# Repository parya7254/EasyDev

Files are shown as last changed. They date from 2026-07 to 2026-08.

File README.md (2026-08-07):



# EasyDev
A RP2040 Dev Board featuring 43 exposed pins along with 16 MB of flash storage! Can support up to (not recommended) 1A of power draw on VBUS! Features 29 programmable GPIO pins so that you have plenty of pins for plenty of connecting and tinkering and also a onboard NeoPixel-compatible addressable RGB LED with a exposed pin dedicated for connecting other addressable LEDs to the board without sacrificing a GPIO!




# Why?
I was thinking of making some PCBs, and I thought, why not try something advanced and also something that you have been wanting to do for a while now? And that's when I came up with the idea of making my own RP2040 dev board (basically a Raspberry Pi Pico) starting from scratch. So I did, and learned a lot along the way! Making this devboard will definitely change the way I make PCBs in the future especially because of all the things that I learned from designing this.

# Using the EasyDev Devboard:
Using EasyDev is pretty similar to using other devboards. To use it simply connect the USB port on the devboard to your computer via a USB-C to USB-C/A cable. Then, simply write code to it like you would to a normal devboard/Arduino. To write the code, you can use CircuitPython/Micropython to program it as those are commonly used programming languages for RP2040 devboard, but if you prefer Arduino IDE, you can also use it. Then, if your program needs any connecting to external components, use 2.54mm dupont jumper wires to connect the parts to your devboard!

# Assembly:
The EasyDev devboard comes preassembled <ins>except for the header pins.</ins> You will have to solder the header pins on yourself. The max temperature recommended for soldering is 350 Degrees Celsius, but you should keep the temperature as low as possible <ins> to avoid damaging the PCB,</ins> but not too low where the solder won't properly melt and flow smoothly.

# How it Works:
If you are curious of how this devboard works, well you are in the right spot! When you connect the devboard to your computer, power goes through something called a LDO (Low Dropout Regulator) which, in our case, will keep the voltage going to the rest of the board at 3.3V. But why 3.3V, you might ask. Well, this is because the chip/microcontroller that the devboard has uses 3.3V logic and can only take 3.3V of power, your USB port has 5V of power, directly wiring the USB pins to the chip would blow it up! Then the power goes through decoupling capacitors which are like tiny batteries and then the capacitors help keep stable voltages to the RP2040 chip in case the voltage drops.  Then, there are pins on the chip called GPIOs (General Purpose Input/Output) that you can control with code. Those pins are wired to the header pins on the left and right-hand side. And then the USB data lines are also connected to the RP2040 so that the computer and the devboard can communicate with each other and to upload code to the board. And after you program the board, you can connect parts to the pins like motors, LEDs, etc. using some wires and/or a breadboard!

# PCB




# Schematic


# BOM
Parts used for PCBA:
| Item # | Part Name | JLC Part # | Source | Cost (USD) | Link |
| -----: | :--- | :--- | :----- | ---: | :--- |
| 1 | 1uF 25V X5R ±10% 0402 MLCC Capacitor | **C52923** | JLCPCB | $0.2650 | [https://jlcpcb.com/partdetail/53938-CL05A105KA5NQNC/C52923](https://jlcpcb.com/partdetail/53938-CL05A105KA5NQNC/C52923) |
| 2 | 100nF 16V X7R ±10% 0402 MLCC Capacitor | **C1525** | JLCPCB | $0.2915 | [https://jlcpcb.com/partdetail/1877-CL05B104KO5NNNC/C1525](https://jlcpcb.com/partdetail/1877-CL05B104KO5NNNC/C1525) |
| 3 | 10µF 10V X5R ±10% 0603 MLCC Capacitor | **C19702** | JLCPCB | $0.4080 | [https://jlcpcb.com/partdetail/20411-CL10A106KP8NNNC/C19702](https://jlcpcb.com/partdetail/20411-CL10A106KP8NNNC/C19702) |
| 4 | 33pF 50V C0G ±5% 0402 MLCC Capacitor | **C1562** | JLCPCB | $0.1410 | [https://jlcpcb.com/partdetail/1914-0402CG330J500NT/C1562](https://jlcpcb.com/partdetail/1914-0402CG330J500NT/C1562) |
| 5 | WS2812B-2020V6 RGB LED (Built-in IC) | **C52917434** | JLCPCB | $0.8118 | [https://jlcpcb.com/partdetail/Worldsemi-WS2812B_2020V6/C52917434](https://jlcpcb.com/partdetail/Worldsemi-WS2812B_2020V6/C52917434) |
| 6 | USB Type-C Connector (16P, Right Angle SMT) | **C165948** | JLCPCB | $0.9205 | [https://jlcpcb.com/partdetail/Korean_HropartsElec-TYPE_C_31_M12/C165948](https://jlcpcb.com/partdetail/Korean_HropartsElec-TYPE_C_31_M12/C165948) |
| 7 | 5.1kΩ 0402 ±1% Resistor | **C25905** | JLCPCB | $0.0670 | [https://jlcpcb.com/partdetail/26648-0402WGF5101TCE/C25905](https://jlcpcb.com/partdetail/26648-0402WGF5101TCE/C25905) |
| 8 | 27Ω 0402 ±1% Resistor | **C138021** | JLCPCB | $0.1034 | [https://jlcpcb.com/partdetail/YAGEO-RC0402FR0727RL/C138021](https://jlcpcb.com/partdetail/YAGEO-RC0402FR0727RL/C138021) |
| 9 | 1kΩ 0402 ±1% Resistor | **C11702** | JLCPCB | $0.0800 | [https://jlcpcb.com/partdetail/12256-0402WGF1001TCE/C11702](https://jlcpcb.com/partdetail/12256-0402WGF1001TCE/C11702) |
| 10 | 10kΩ 0402 ±1% Resistor | **C60490** | JLCPCB | $0.1160 | [https://jlcpcb.com/partdetail/YAGEO-RC0402FR0710KL/C60490](https://jlcpcb.com/partdetail/YAGEO-RC0402FR0710KL/C60490) |
| 11 | 4×3mm SMT Tactile Switch | **C720477** | JLCPCB | $0.2760 | [https://jlcpcb.com/partdetail/XUNPU-TS_1088AR02016/C720477](https://jlcpcb.com/partdetail/XUNPU-TS_1088AR02016/C720477) |
| 12 | RP2040 Microcontroller | **C2040** | JLCPCB | $4.9250 | [https://jlcpcb.com/partdetail/RaspberryPi-RP2040/C2040](https://jlcpcb.com/partdetail/RaspberryPi-RP2040/C2040) |
| 13 | NCP1117ST33T3G 3.3V LDO Regulator | **C26537** | JLCPCB | $1.1680 | [https://jlcpcb.com/partdetail/onsemi-NCP1117ST33T3G/C26537](https://jlcpcb.com/partdetail/onsemi-NCP1117ST33T3G/C26537) |
| 14 | W25Q16JVUXIQ 16Mbit SPI Flash | **C2843335**  | JLCPCB | $10.1720 | [https://jlcpcb.com/partdetail/WinbondElec-W25Q16JVUXIQ/C2843335](https://jlcpcb.com/partdetail/WinbondElec-W25Q16JVUXIQ/C2843335) |
| 15 | 12MHz SMD Crystal | **C9002** | JLCPCB | $0.4750 | [https://jlcpcb.com/partdetail/YXC_CrystalOscillators-X322512MSB4SI/C9002](https://jlcpcb.com/partdetail/YXC_CrystalOscillators-X322512MSB4SI/C9002) |

# OLD PCB!!


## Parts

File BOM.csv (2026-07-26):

JLCPCB BOM Tool - BOM Matching
BOM name：EasyDev-PCBA-BOM-JLCPCB-Format-JLCPCB Assembly Order.xlsx |  |  | Download Time：2026-07-27 05:19:50 |  |  |  | * Our matching results are updated in real-time, but stock and prices may change. If it's been over 24 hours, please re-match before placing your order.
PCB Assembled Qty：5 |  |  | Est. Total Price：20.2202
Your BOM |  |  |  |  | Matched Parts |  |  |  |  |  |  | Order Information
Top Designator | Bottom Designator | Comment | Footprint | JLCPCB Part # | Matches | Part # | Manufacturer | Footprint | Description | Category | Warning | JLCPCB Part # | Product link | Lib Type | Qty | Source | Total Price ($)
C1,C10 |  | 1uF | C_0402_1005Metric |  | Select by Customer | CL05A105KA5NQNC | Samsung Electro-Mechanics | 0402 | 1uF 25V X5R ±10% 0402 Multilayer Ceramic Capacitors MLCC - SMD/SMT ROHS | Multilayer Ceramic Capacitors MLCC - SMD/SMT |  | C52923 | https://jlcpcb.com/partdetail/53938-CL05A105KA5NQNC/C52923 | Basic | 10 | 10 JLCPCB | 0.265
C7,C8,C17,C4,C12,C9,C11,C5,C3,C2,C6 |  | 0.1uF | C_0402_1005Metric |  | Select by Customer | CL05B104KO5NNNC | Samsung Electro-Mechanics | 0402 | 100nF 16V X7R ±10% 0402 Multilayer Ceramic Capacitors MLCC - SMD/SMT ROHS | Multilayer Ceramic Capacitors MLCC - SMD/SMT | 1.The comment (CL05B104KO5NNNC) of this part does not match the one (0.1uF) provided in your BOM. Please confirm; | C1525 | https://jlcpcb.com/partdetail/1877-CL05B104KO5NNNC/C1525 | Basic | 55 | 55 JLCPCB | 0.2915
C14,C13 |  | 10uF | C_0603_1608Metric |  | Select by Customer | CL10A106KP8NNNC | Samsung Electro-Mechanics | 0603 | 10V 10uF X5R ±10% 0603 Multilayer Ceramic Capacitors MLCC - SMD/SMT ROHS | Multilayer Ceramic Capacitors MLCC - SMD/SMT |  | C19702 | https://jlcpcb.com/partdetail/20411-CL10A106KP8NNNC/C19702 | Basic | 10 | 10 JLCPCB | 0.408
C16,C15 |  | 33pF | C_0402_1005Metric |  | Select by Customer | 0402CG330J500NT | FH (Guangdong Fenghua Advanced Tech) | 0402 | 33pF 50V C0G ±5% 0402 Multilayer Ceramic Capacitors MLCC - SMD/SMT ROHS | Multilayer Ceramic Capacitors MLCC - SMD/SMT |  | C1562 | https://jlcpcb.com/partdetail/1914-0402CG330J500NT/C1562 | Basic | 10 | 10 JLCPCB | 0.141
D1 |  | WS2812B-2020 | LED_WS2812B-2020_PLCC4_2.0x2.0mm |  | Select by Customer | WS2812B-2020-V6 | Worldsemi | SMD2020-4P | Built-in power-on reset circuit、Built-in power-on reset circuit、Integrated intelligent reverse connection protection function SMD2020-4P RGB LEDs(Built-in IC) ROHS |  |  | C52917434 | https://jlcpcb.com/partdetail/Worldsemi-WS2812B_2020V6/C52917434 | Extended | 9 | 9 JLCPCB | 0.8118
J1 |  | USB_C_Receptacle_USB2.0_14P | USB_C_Receptacle_HRO_TYPE-C-31-M-12 |  | Select by Customer | TYPE-C-31-M-12 | Korean Hroparts Elec | SMD | -30℃~+80℃ 1 10,000 cycles 16P 20V 5A 7.35mm Female Surface Mount, Right Angle Type-C SMD USB Connectors ROHS | USB Connectors |  | C165948 | https://jlcpcb.com/partdetail/Korean_HropartsElec-TYPE_C_31_M12/C165948 | Extended | 5 | 5 JLCPCB | 0.9205
R1,R2 |  | 5.1K | R_0402_1005Metric |  | Select by Customer | 0402WGF5101TCE | UNI-ROYAL(Uniroyal Elec) | 0402 | -55℃~+155℃ 5.1kΩ 50V 62.5mW Thick Film Resistor ±1% ±100ppm/℃ 0402 Chip Resistor - Surface Mount ROHS | Chip Resistor - Surface Mount |  | C25905 | https://jlcpcb.com/partdetail/26648-0402WGF5101TCE/C25905 | Basic | 10 | 10 JLCPCB | 0.067
R4,R3 |  | 27 | R_0402_1005Metric |  | Select by Customer | RC0402FR-0727RL | YAGEO | 0402 | -55℃~+155℃ 27Ω 50V 62.5mW Thick Film Resistor ±1% ±100ppm/℃ 0402 Chip Resistor - Surface Mount ROHS | Chip Resistor - Surface Mount | 1.The comment (RC0402FR-0727RL) of this part does not match the one (27) provided in your BOM. Please confirm; | C138021 | https://jlcpcb.com/partdetail/YAGEO-RC0402FR0727RL/C138021 | Extended | 22 | 22 JLCPCB | 0.1034
R5,R6 |  | 1K | R_0402_1005Metric |  | Select by Customer | 0402WGF1001TCE | UNI-ROYAL(Uniroyal Elec) | 0402 | -55℃~+155℃ 1kΩ 50V 62.5mW Thick Film Resistor ±1% ±100ppm/℃ 0402 Chip Resistor - Surface Mount ROHS | Chip Resistor - Surface Mount | 1.The comment (0402WGF1001TCE) of this part does not match the one (1K) provided in your BOM. Please confirm; | C11702 | https://jlcpcb.com/partdetail/12256-0402WGF1001TCE/C11702 | Basic | 10 | 10 JLCPCB | 0.08
R7 |  | 10K | R_0402_1005Metric |  | Select by Customer | RC0402FR-0710KL | YAGEO | 0402 | -55℃~+155℃ 10kΩ 50V 62.5mW Thick Film Resistor ±1% ±100ppm/℃ 0402 Chip Resistor - Surface Mount ROHS | Chip Resistor - Surface Mount | 1.The comment (RC0402FR-0710KL) of this part does not match the one (10K) provided in your BOM. Please confirm; | C60490 | https://jlcpcb.com/partdetail/YAGEO-RC0402FR0710KL/C60490 | Extended | 20 | 20 JLCPCB | 0.116
SW1 |  | SW_Push | SW_Push_SPST_NO_Alps_SKRK |  | Select by Customer | TS-1088-AR02016 | XUNPU | SMD,4x3mm | -30℃~+80℃ 1.6N 100,000 cycles 12V 2mm 3.9mm 3mm 50mA Black Round Button SMD(SMT) Tab SPST Surface Mount,Vertical Without Bracket SMD,4x3mm Tactile Switches ROHS | Tactile Switches |  | C720477 | https://jlcpcb.com/partdetail/XUNPU-TS_1088AR02016/C720477 | Basic | 5 | 5 JLCPCB | 0.276
U1 |  | RP2040 | QFN-56-1EP_7x7mm_P0.4mm_EP3.2x3.2mm |  | Select by Customer | RP2040 | Raspberry Pi | LQFN-56(7x7) | 12bit 133MHz 30 LQFN-56(7x7) Microcontrollers (MCU/MPU/SOC) ROHS | Microcontrollers (MCU/MPU/SOC) |  | C2040 | https://jlcpcb.com/partdetail/RaspberryPi-RP2040/C2040 | Extended | 5 | 5 JLCPCB | 4.925
U2 |  | NCP1117-3.3_SOT223 | SOT-223-3_TabPin2 |  | Select by Customer | NCP1117ST33T3G | onsemi | SOT-223 | 0.003%Vout 0℃~+125℃@(Ta) 1 1.2V@(800mA) 1A 20V 3.3V 62dB@(120Hz) 6mA Fixed Over Current Protection、Thermal Shutdown Positive SOT-223 Voltage Regulators - Linear, Low Drop Out (LDO) Regulators ROHS | Voltage Regulators - Linear, Low Drop Out (LDO) Regulators |  | C26537 | https://jlcpcb.com/partdetail/onsemi-NCP1117ST33T3G/C26537 | Extended | 5 | 5 JLCPCB | 1.168
U3 |  | W25Q128JVS | Winbond_USON-8-1EP_3x2mm_P0.5mm_EP0.2x1.6mm |  | Select by Customer | W25Q16JVUXIQ | Winbond Elec | USON-8-EP(2x3) | -40℃~+85℃ 100,000 cycles 10uA 133MHz 16Mbit 2.7V~3.6V 20 Years 3ms SPI USON-8-EP(2x3) NOR FLASH ROHS | NOR FLASH | 1.The comment (W25Q16JVUXIQ) of this part does not match the one (W25Q128JVS) provided in your BOM. Please confirm; | C2843335 | https://jlcpcb.com/partdetail/WinbondElec-W25Q16JVUXIQ/C2843335 | Extended | 5 | 5 JLCPCB | 10.172
Y1 |  | 12MHz | Crystal_SMD_3225-4Pin_3.2x2.5mm |  | Select by Customer | X322512MSB4SI | YXC Crystal Oscillators | SMD3225-4P | -40℃~+85℃ 12MHz 20pF Crystal Oscillator ±10ppm ±20ppm SMD3225-4P Crystals ROHS | Crystals |  | C9002 | https://jlcpcb.com/partdetail/YXC_CrystalOscillators-X322512MSB4SI/C9002 | Basic | 5 | 5 JLCPCB | 0.475
J3,J2 |  | Conn_01x20 | PinSocket_1x20_P2.54mm_Vertical |  | No matches | No Part Selected
J4 |  | Conn_01x03 | PinSocket_1x03_P2.54mm_Vertical |  | No matches | No Part Selected
J5 |  | Conn_01x01 | PinSocket_1x01_P2.54mm_Vertical |  | No matches | No Part Selected

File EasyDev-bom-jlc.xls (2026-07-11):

JLCPCB BOM Tool - BOM Matching
BOM name：EasyDev-JLCPCB Assembly Order.xlsx |  |  | Download Time：2026-07-11 04:36:07 |  |  |  | * Our matching results are updated in real-time, but stock and prices may change. If it's been over 24 hours, please re-match before placing your order.
PCB Assembled Qty：5 |  |  | Est. Total Price：20.5190
Your BOM |  |  |  |  | Matched Parts |  |  |  |  |  |  | Order Information
Top Designator | Bottom Designator | Comment | Footprint | JLCPCB Part # | Matches | Part # | Manufacturer | Footprint | Description | Category | Warning | JLCPCB Part # | Product link | Lib Type | Qty | Source | Total Price ($)
C1,C10 |  | 1uF | C_0402_1005Metric |  | Select by Customer | CL05A105KA5NQNC | Samsung Electro-Mechanics | 0402 | 1uF 25V X5R ±10% 0402 Multilayer Ceramic Capacitors MLCC - SMD/SMT ROHS | Multilayer Ceramic Capacitors MLCC - SMD/SMT |  | C52923 | https://jlcpcb.com/partdetail/53938-CL05A105KA5NQNC/C52923 | Basic | 10 | 10 JLCPCB | 0.264
C7,C8,C17,C4,C12,C9,C11,C5,C3,C2,C6 |  | 0.1uF | C_0402_1005Metric |  | Select by Customer | CL05B104KO5NNNC | Samsung Electro-Mechanics | 0402 | 100nF 16V X7R ±10% 0402 Multilayer Ceramic Capacitors MLCC - SMD/SMT ROHS | Multilayer Ceramic Capacitors MLCC - SMD/SMT | 1.The comment (CL05B104KO5NNNC) of this part does not match the one (0.1uF) provided in your BOM. Please confirm; | C1525 | https://jlcpcb.com/partdetail/1877-CL05B104KO5NNNC/C1525 | Basic | 55 | 55 JLCPCB | 0.3795
C14,C13 |  | 10uF | C_0603_1608Metric |  | Select by System | CL10A106KP8NNNC | Samsung Electro-Mechanics | 0603 | 10V 10uF X5R ±10% 0603 Multilayer Ceramic Capacitors MLCC - SMD/SMT ROHS | Multilayer Ceramic Capacitors MLCC - SMD/SMT |  | C19702 | https://jlcpcb.com/partdetail/20411-CL10A106KP8NNNC/C19702 | Basic | 10 | 10 JLCPCB | 1.037
C16,C15 |  | 33pF | C_0402_1005Metric |  | Select by Customer | 0402CG330J500NT | FH (Guangdong Fenghua Advanced Tech) | 0402 | 33pF 50V C0G ±5% 0402 Multilayer Ceramic Capacitors MLCC - SMD/SMT ROHS | Multilayer Ceramic Capacitors MLCC - SMD/SMT |  | C1562 | https://jlcpcb.com/partdetail/1914-0402CG330J500NT/C1562 | Basic | 10 | 10 JLCPCB | 0.113
J1 |  | USB_C_Receptacle_USB2.0_14P | USB_C_Receptacle_HRO_TYPE-C-31-M-12 |  | Select by Customer | TYPE-C-31-M-12 | Korean Hroparts Elec | SMD | -30℃~+80℃ 1 10,000 cycles 16P 20V 5A 7.35mm Female Surface Mount, Right Angle Type-C SMD USB Connectors ROHS | USB Connectors |  | C165948 | https://jlcpcb.com/partdetail/Korean_HropartsElec-TYPE_C_31_M12/C165948 | Extended | 5 | 5 JLCPCB | 0.9175
J3,J2 |  | Conn_01x20 | PinSocket_1x20_P2.54mm_Vertical |  | Select by Customer | 2.54-1*20P直针 | BOOMELE(Boom Precision Elec) | 插件,P=2.54mm | -40℃~+105℃ 1 1x20P 2.54mm 20P 3A Black Brass Pin Header Through Hole 插件,P=2.54mm Pin Headers ROHS | Pin Headers |  | C50981 | https://jlcpcb.com/partdetail/51993-2_54_1_20P/C50981 | Extended | 0 | 0 JLCPCB | 0
J4 |  | Conn_01x03 | PinSocket_1x03_P2.54mm_Vertical |  | Select by Customer | 1.27-1*3P针 | BOOMELE(Boom Precision Elec) | 插件,P=1.27mm | -55℃~+105℃ 1 1.27mm 1.7mm 1x3P 2.5mm 3A 3P 3mm Black Brass Pin Header Through Hole 插件,P=1.27mm Pin Headers ROHS | Pin Headers |  | C24980 | https://jlcpcb.com/partdetail/25717-1_27_1_3P/C24980 | Extended | 0 | 0 JLCPCB | 0
R1,R2 |  | 5.1K | R_0402_1005Metric |  | Select by Customer | 0402WGF5101TCE | UNI-ROYAL(Uniroyal Elec) | 0402 | -55℃~+155℃ 5.1kΩ 50V 62.5mW Thick Film Resistor ±1% ±100ppm/℃ 0402 Chip Resistor - Surface Mount ROHS | Chip Resistor - Surface Mount |  | C25905 | https://jlcpcb.com/partdetail/26648-0402WGF5101TCE/C25905 | Basic | 10 | 10 JLCPCB | 0.014
R4,R3 |  | 27 | R_0402_1005Metric |  | Select by Customer | RTT0227R0FTH | RALEC | 0402 | -55℃~+155℃ 27Ω 50V 62.5mW Thick Film Resistor ±1% ±100ppm/℃ 0402 Chip Resistor - Surface Mount ROHS | Chip Resistor - Surface Mount | 1.The comment (RTT0227R0FTH) of this part does not match the one (27) provided in your BOM. Please confirm; | C102944 | https://jlcpcb.com/partdetail/RALEC-RTT0227R0FTH/C102944 | Extended | 20 | 20 JLCPCB | 0.058
R5,R6 |  | 1K | R_0402_1005Metric |  | Select by Customer | 0402WGF1001TCE | UNI-ROYAL(Uniroyal Elec) | 0402 | -55℃~+155℃ 1kΩ 50V 62.5mW Thick Film Resistor ±1% ±100ppm/℃ 0402 Chip Resistor - Surface Mount ROHS | Chip Resistor - Surface Mount | 1.The comment (0402WGF1001TCE) of this part does not match the one (1K) provided in your BOM. Please confirm; | C11702 | https://jlcpcb.com/partdetail/12256-0402WGF1001TCE/C11702 | Basic | 10 | 10 JLCPCB | 0.05
R7 |  | 10K | R_0402_1005Metric |  | Select by Customer | 0402WGF1002TCE | UNI-ROYAL(Uniroyal Elec) | 0402 | -55℃~+155℃ 10kΩ 50V 62.5mW Thick Film Resistor ±1% ±100ppm/℃ 0402 Chip Resistor - Surface Mount ROHS | Chip Resistor - Surface Mount | 1.The comment (0402WGF1002TCE) of this part does not match the one (10K) provided in your BOM. Please confirm; | C25744 | https://jlcpcb.com/partdetail/26487-0402WGF1002TCE/C25744 | Basic | 5 | 5 JLCPCB | 0.011
SW1 |  | SW_Push | SW_Push_SPST_NO_Alps_SKRK |  | Select by Customer | TS-1088-AR02016 | XUNPU | SMD,4x3mm | -30℃~+80℃ 1.6N 100,000 cycles 12V 2mm 3.9mm 3mm 50mA Black Round Button SMD(SMT) Tab SPST Surface Mount,Vertical Without Bracket SMD,4x3mm Tactile Switches ROHS | Tactile Switches |  | C720477 | https://jlcpcb.com/partdetail/XUNPU-TS_1088AR02016/C720477 | Basic | 5 | 5 JLCPCB | 0.275
U1 |  | RP2040 | QFN-56-1EP_7x7mm_P0.4mm_EP3.2x3.2mm |  | Select by Customer | RP2040 | Raspberry Pi | LQFN-56(7x7) | 12bit 133MHz 30 LQFN-56(7x7) Microcontrollers (MCU/MPU/SOC) ROHS | Microcontrollers (MCU/MPU/SOC) |  | C2040 | https://jlcpcb.com/partdetail/RaspberryPi-RP2040/C2040 | Extended | 5 | 5 JLCPCB | 4.908
U2 |  | NCP1117-3.3_SOT223 | SOT-223-3_TabPin2 |  | Select by Customer | NCP1117ST33T3G | onsemi | SOT-223 | 0.003%Vout 0℃~+125℃@(Ta) 1 1.2V@(800mA) 1A 20V 3.3V 62dB@(120Hz) 6mA Fixed Over Current Protection、Thermal Shutdown Positive SOT-223 Voltage Regulators - Linear, Low Drop Out (LDO) Regulators ROHS | Voltage Regulators - Linear, Low Drop Out (LDO) Regulators |  | C26537 | https://jlcpcb.com/partdetail/onsemi-NCP1117ST33T3G/C26537 | Extended | 5 | 5 JLCPCB | 1.263
U3 |  | W25Q128JVS | Winbond_USON-8-1EP_3x2mm_P0.5mm_EP0.2x1.6mm |  | Select by Customer | W25Q16JVUXIQ | Winbond Elec | USON-8-EP(2x3) | -40℃~+85℃ 100,000 cycles 10uA 133MHz 16Mbit 2.7V~3.6V 20 Years 3ms SPI USON-8-EP(2x3) NOR FLASH ROHS | NOR FLASH | 1.The comment (W25Q16JVUXIQ) of this part does not match the one (W25Q128JVS) provided in your BOM. Please confirm; | C2843335 | https://jlcpcb.com/partdetail/WinbondElec-W25Q16JVUXIQ/C2843335 | Extended | 5 | 5 JLCPCB | 10.731
Y1 |  | 12MHz | Crystal_SMD_3225-4Pin_3.2x2.5mm |  | Select by Customer | X322512MSB4SI | YXC Crystal Oscillators | SMD3225-4P | -40℃~+85℃ 12MHz 20pF Crystal Oscillator ±10ppm ±20ppm SMD3225-4P Crystals ROHS | Crystals |  | C9002 | https://jlcpcb.com/partdetail/YXC_CrystalOscillators-X322512MSB4SI/C9002 | Basic | 5 | 5 JLCPCB | 0.498

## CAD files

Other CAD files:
CAD/EasyDev-3D Model.step

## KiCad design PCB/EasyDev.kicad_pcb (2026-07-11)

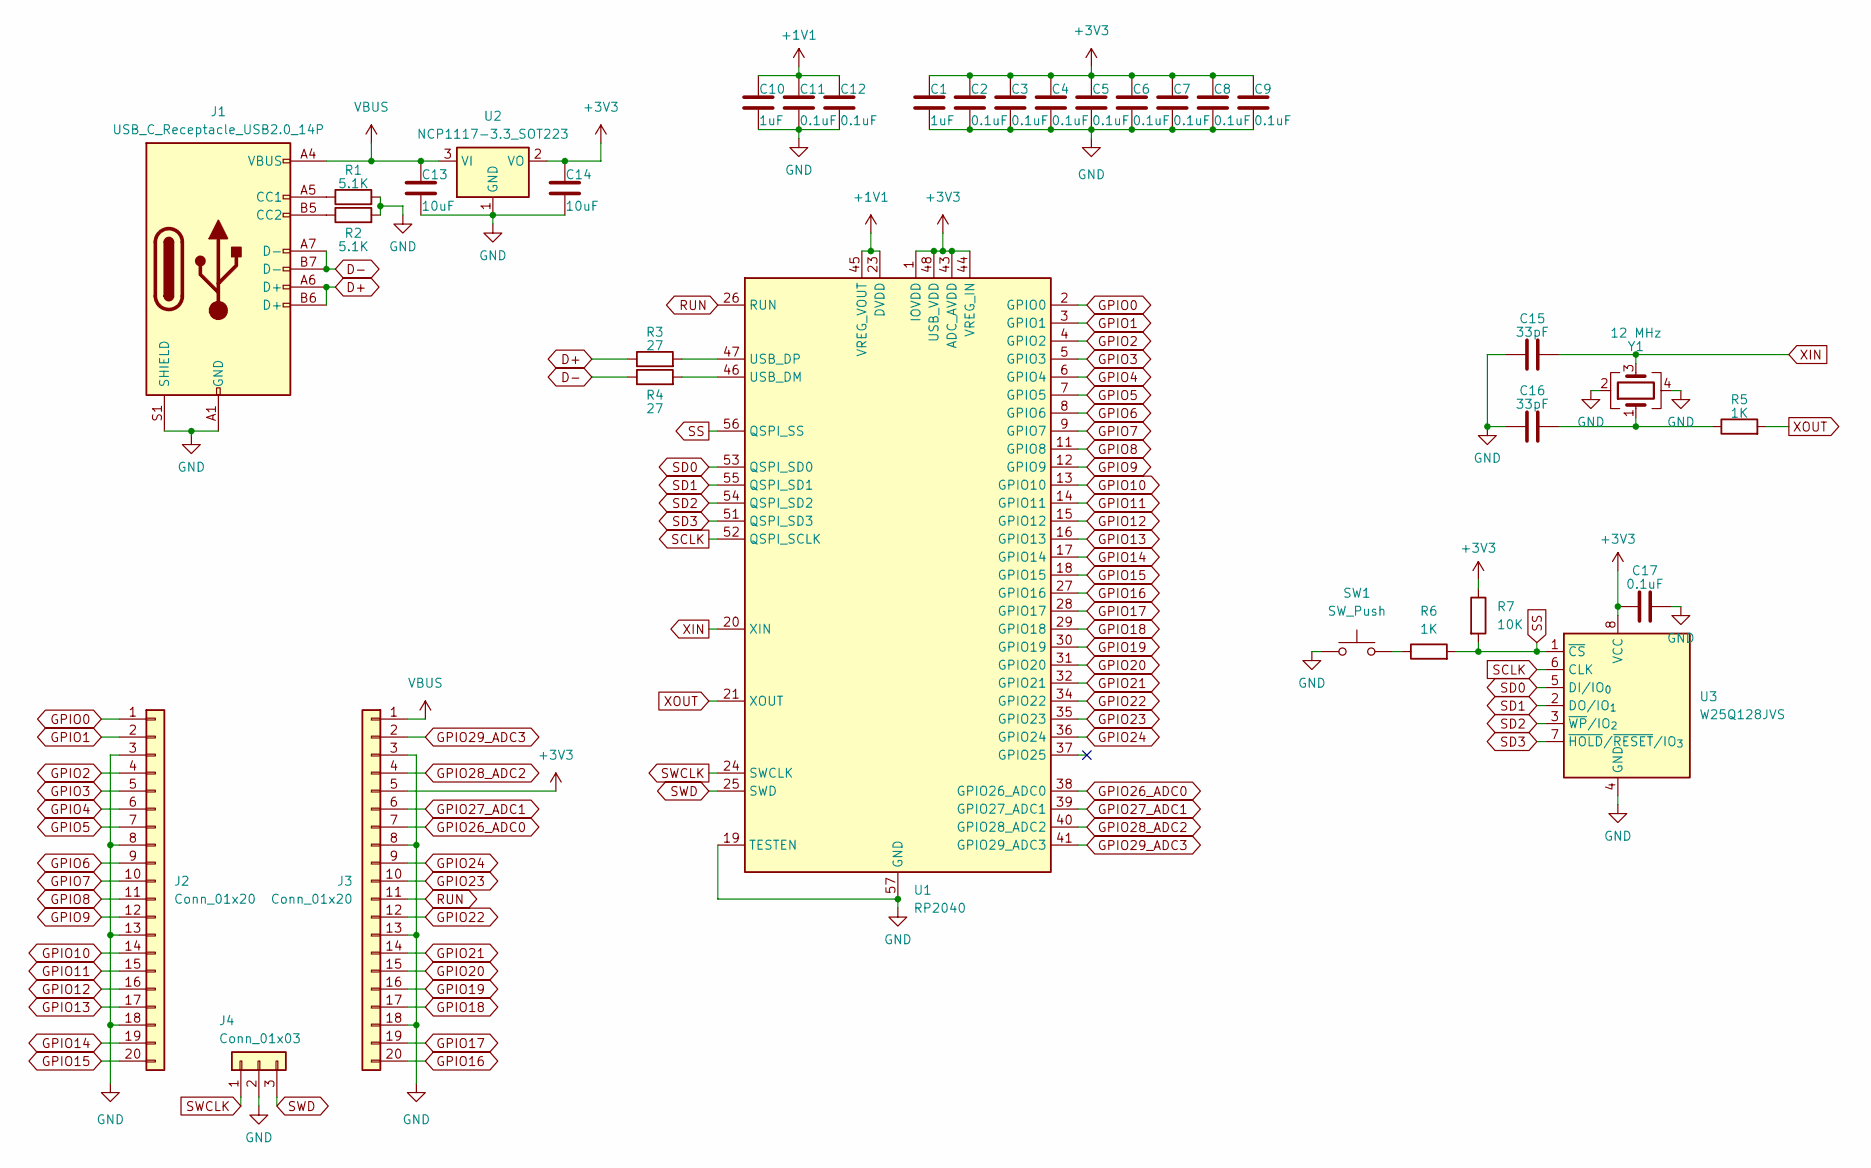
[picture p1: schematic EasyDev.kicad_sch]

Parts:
C1, C10: 1uF; C_0402_1005Metric
C2, C3, C4, C5, C6, C7, C8, C9, C11, C12, C17: 0.1uF; C_0402_1005Metric
C13, C14: 10uF; C_0603_1608Metric
C15, C16: 33pF; C_0402_1005Metric
J1: USB_C_Receptacle_USB2.0_14P; USB_C_Receptacle_HRO_TYPE-C-31-M-12
J2, J3: Conn_01x20; PinSocket_1x20_P2.54mm_Vertical
J4: Conn_01x03; PinSocket_1x03_P2.54mm_Vertical
R1, R2: 5.1K; R_0402_1005Metric
R3, R4: 27; R_0402_1005Metric
R5, R6: 1K; R_0402_1005Metric
R7: 10K; R_0402_1005Metric
SW1: SW_Push; SW_Push_SPST_NO_Alps_SKRK
U1: RP2040; QFN-56-1EP_7x7mm_P0.4mm_EP3.2x3.2mm
U2: NCP1117-3.3_SOT223; SOT-223-3_TabPin2
U3: W25Q128JVS; Winbond_USON-8-1EP_3x2mm_P0.5mm_EP0.2x1.6mm
Y1: 12 MHz; Crystal_SMD_3225-4Pin_3.2x2.5mm

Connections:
+1V1: C10.1, C11.1, C12.1, U1.23 (DVDD), U1.45 (VREG_VOUT), U1.50 (DVDD)
+3V3: C1.1, C2.1, C3.1, C4.1, C5.1, C6.1, C7.1, C8.1, C9.1, C14.1, C17.1, J3.5, R7.1, U1.1 (IOVDD), U1.10 (IOVDD), U1.22 (IOVDD), U1.33 (IOVDD), U1.42 (IOVDD), U1.43 (ADC_AVDD), U1.44 (VREG_IN), U1.48 (USB_VDD), U1.49 (IOVDD), U2.2 (VO), U3.8 (VCC)
D+: J1.A6 (D+), J1.B6 (D+), R3.1
D-: J1.A7 (D-), J1.B7 (D-), R4.1
GND: C1.2, C2.2, C3.2, C4.2, C5.2, C6.2, C7.2, C8.2, C9.2, C10.2, C11.2, C12.2, C13.2, C14.2, C15.1, C16.1, C17.2, J1.A1 (GND), J1.A12 (GND), J1.B1 (GND), J1.B12 (GND), J1.S1 (SHIELD), J2.3, J2.8, J2.13, J2.18, J3.3, J3.8, J3.13, J3.18, J4.2, R1.2, R2.2, SW1.1, U1.19 (TESTEN), U1.57 (GND), U2.1 (GND), U3.4 (GND), Y1.2, Y1.4
GPIO0: J2.1, U1.2 (GPIO0)
GPIO1: J2.2, U1.3 (GPIO1)
GPIO2: J2.4, U1.4 (GPIO2)
GPIO3: J2.5, U1.5 (GPIO3)
GPIO4: J2.6, U1.6 (GPIO4)
GPIO5: J2.7, U1.7 (GPIO5)
GPIO6: J2.9, U1.8 (GPIO6)
GPIO7: J2.10, U1.9 (GPIO7)
GPIO8: J2.11, U1.11 (GPIO8)
GPIO9: J2.12, U1.12 (GPIO9)
GPIO10: J2.14, U1.13 (GPIO10)
GPIO11: J2.15, U1.14 (GPIO11)
GPIO12: J2.16, U1.15 (GPIO12)
GPIO13: J2.17, U1.16 (GPIO13)
GPIO14: J2.19, U1.17 (GPIO14)
GPIO15: J2.20, U1.18 (GPIO15)
GPIO16: J3.20, U1.27 (GPIO16)
GPIO17: J3.19, U1.28 (GPIO17)
GPIO18: J3.17, U1.29 (GPIO18)
GPIO19: J3.16, U1.30 (GPIO19)
GPIO20: J3.15, U1.31 (GPIO20)
GPIO21: J3.14, U1.32 (GPIO21)
GPIO22: J3.12, U1.34 (GPIO22)
GPIO23: J3.10, U1.35 (GPIO23)
GPIO24: J3.9, U1.36 (GPIO24)
GPIO26_ADC0: J3.7, U1.38 (GPIO26_ADC0)
GPIO27_ADC1: J3.6, U1.39 (GPIO27_ADC1)
GPIO28_ADC2: J3.4, U1.40 (GPIO28_ADC2)
GPIO29_ADC3: J3.2, U1.41 (GPIO29_ADC3)
unnamed: C16.2, R5.1, Y1.1
unnamed: J1.A5 (CC1), R1.1
unnamed: J1.B5 (CC2), R2.1
unnamed: R6.1, SW1.2
unnamed: R4.2, U1.46 (USB_DM)
unnamed: R3.2, U1.47 (USB_DP)
RUN: J3.11, U1.26 (RUN)
SCLK: U1.52 (QSPI_SCLK), U3.6 (CLK)
SD0: U1.53 (QSPI_SD0), U3.5 (DI/IO_{0})
SD1: U1.55 (QSPI_SD1), U3.2 (DO/IO_{1})
SD2: U1.54 (QSPI_SD2), U3.3 (~WP/IO_{2})
SD3: U1.51 (QSPI_SD3), U3.7 (~HOLD/~RESET/IO_{3})
SS: R6.2, R7.2, U1.56 (QSPI_SS), U3.1 (~CS)
SWCLK: J4.1, U1.24 (SWCLK)
SWD: J4.3, U1.25 (SWD)
VBUS: C13.1, J1.A4 (VBUS), J1.A9 (VBUS), J1.B4 (VBUS), J1.B9 (VBUS), J3.1, U2.3 (VI)
XIN: C15.2, U1.20 (XIN), Y1.3
XOUT: R5.2, U1.21 (XOUT)

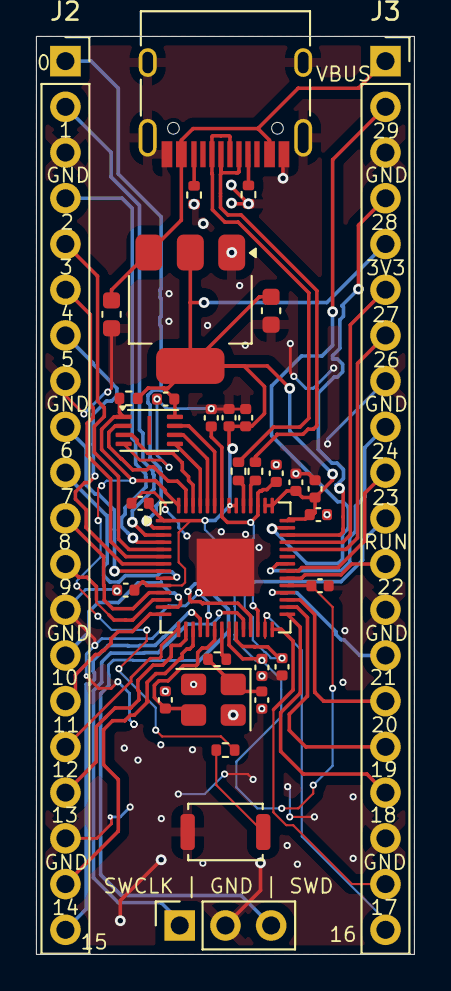
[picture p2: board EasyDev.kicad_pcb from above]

Board: 2 copper layers, 21.0 x 51.0 mm, 33 parts (0 on the bottom side), 52 nets.

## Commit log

2026-07-11 Uploaded Everything!!
    Uploaded all files needed for dev board including: PCB Gerbers, KiCad Files, and PCBA Files!
    [EasyDev-B_Cu.gbr, EasyDev-B_Mask.gbr, EasyDev-B_Paste.gbr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]
2026-07-11 Uploaded BOM Files!!
    [EasyDev-bom-jlc.xls, EasyDev-bom.csv]
2026-07-26 Enhance README with new features and images
    Updated the README to include additional features and images for the RP2040 Dev Board.
2026-07-26 Uploaded Everything!!
    [EasyDev-Component-Placement-Top-JLCPCB-Format.csv, EasyDev-Component-Placement-Top.csv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]
2026-08-06 Enhance README with usage and assembly instructions
    Added sections on usage, assembly, and parts list for the EasyDev devboard.
2026-08-06 Add explanation of EasyDev devboard functionality
    Added a section explaining how the EasyDev devboard works, detailing the power regulation and GPIO functionality.
2026-08-06 Revise BOM entries and update part information
    Updated BOM file with new part details and prices.
    [bom.csv]
2026-08-07 Rename EasyDev-3D Model.step to CAD/EasyDev-3D Model.step
    [EasyDev-3D Model.step]
2026-11-13 Added code to drive LEDs!!
2026-11-13 Refactor PCB images into a table format
    Updated PCB section to use table format for images.
2026-11-14 Update README with project header and old PCB comment
    Added a new header for the project and updated the content to include an old PCB image comment.
2026-11-14 Update BOM with total cost calculation
2026-11-14 Update BOM with PCB cost and total cost
2026-11-14 Fix formatting of PCB and PCBA cost entry in bom.csv
